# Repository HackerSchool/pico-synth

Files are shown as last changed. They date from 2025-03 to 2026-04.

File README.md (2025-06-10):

# pico-synth
The Pico-Synth Board v0.1 is the first version of a Raspberry Pi Pico based synthesizer, featuring an I2S DAC with line-out, a 2x8 switch matrix with individual LEDs, four rotary encoders with switches, an OLED screen, and an SD card slot for optional storage. This fist iteration of the board was designed with a focus on low cost and component availability.

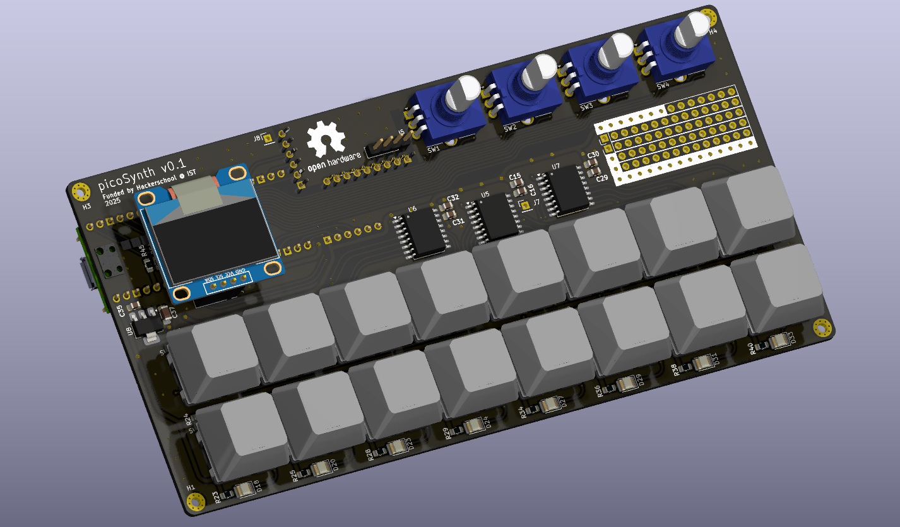
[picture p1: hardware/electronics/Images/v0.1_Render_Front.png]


## 📥 1. Clone the Repository & Initialize Submodules

```sh
git clone --recursive https://github.com/HackerSchool/pico-synth.git
cd pico-synth
```

If you already cloned without `--recursive`, initialize submodules manually:

```sh
git submodule update --init --recursive
```

## 📦 2. Install the Pico SDK and Pico Extras

### **Option 1: Install via Raspberry Pi Repo (Recommended on Raspberry Pi OS)**
```sh
sudo apt install cmake gcc-arm-none-eabi libnewlib-arm-none-eabi build-essential
```

### **Option 2: Manually Install (For Other Linux/Windows/macOS)**
#### **Clone & Set Up the Pico SDK**
```sh
mkdir -p ~/pico && cd ~/pico
git clone --recursive https://github.com/raspberrypi/pico-sdk.git
cd pico-sdk
git submodule update --init
```

#### **Clone & Set Up Pico Extras**
```sh
cd ~/pico
git clone --recursive https://github.com/raspberrypi/pico-extras.git
```

## 🌍 3. Set Environment Variables (Each Terminal Session)

Before building, set the paths so CMake can find the SDK and extras:

```sh
export PICO_SDK_PATH=~/pico/pico-sdk
export PICO_EXTRAS_PATH=~/pico/pico-extras
```

To make this **permanent**, add these lines to `~/.bashrc` or `~/.zshrc`:

```sh
echo 'export PICO_SDK_PATH=~/pico/pico-sdk' >> ~/.bashrc
echo 'export PICO_EXTRAS_PATH=~/pico/pico-extras' >> ~/.bashrc
source ~/.bashrc
```

## 🛠 4. Build the Project

1. **Create a Build Directory**
```sh
mkdir -p build && cd build
```

2. **Run CMake to Configure the Build**
```sh
cmake ..
```
if using ninja on windows:
```sh
cmake -G "Ninja" ..
```
3. **Compile the Code**
```sh
make -j$(nproc)
```
if using ninja on windows:
```sh
ninja
```
## 🔥 5. Flash to the Raspberry Pi Pico

### **Step 1: Put the Pico in Bootloader Mode**
- Hold down the **BOOTSEL** button on the Pico.
- Plug it into your computer via **USB**.
- It should appear as a **USB mass storage device** (RPI-RP2).

### **Step 2: Copy the `.uf2` Binary to the Pico**

Once built, the `pico-synth` binary (`.uf2` file) will be in `build/`:
```sh
cp build/pico-synth.uf2 /media/$USER/RPI-RP2/
```

The Pico will automatically reboot and start running the synthesizer!

---

## 🛠 Troubleshooting

- **"pico_sdk_import.cmake not found" error?**
  - Make sure `PICO_SDK_PATH` is set correctly.
  - Try running `source ~/.bashrc`.

- **No `*.uf2` file after `make`?**
  - Check the build log for errors.
  - Ensure `pico_enable_stdio_usb(${bin_name} 1)` is set in `CMakeLists.txt`.

---

## 📜 License
[GPLV3 License](LICENSE)

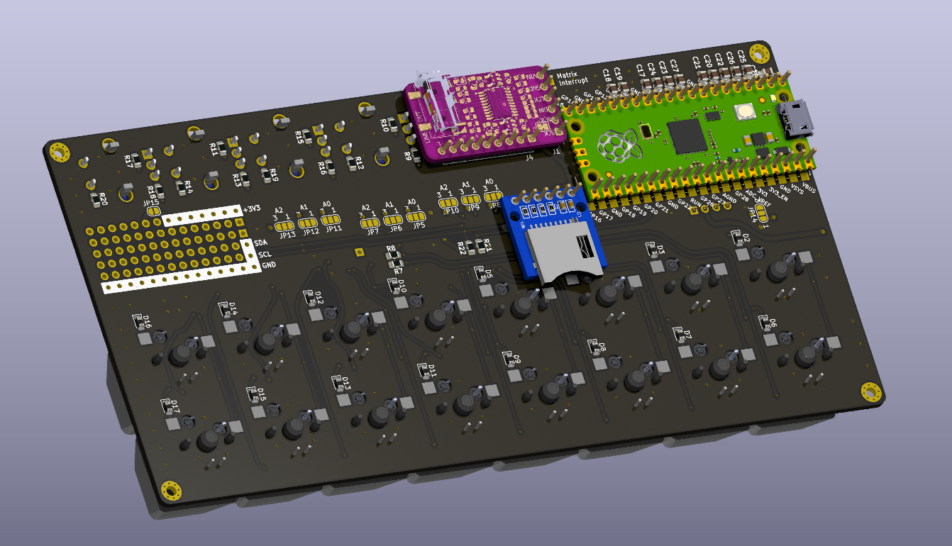
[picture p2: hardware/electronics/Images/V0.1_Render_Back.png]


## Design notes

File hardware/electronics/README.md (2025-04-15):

# Pico Synth Hardware

The Pico-Synth Board v0.1 is the first version of the synthesizer, featuring a DAC with line-out, a 4x4 switch matrix with individual LEDs, four rotary encoders with switches, an OLED screen, and an SD card slot for optional storage. This fist iteration of the board was designed with a focus on low cost and component availability.



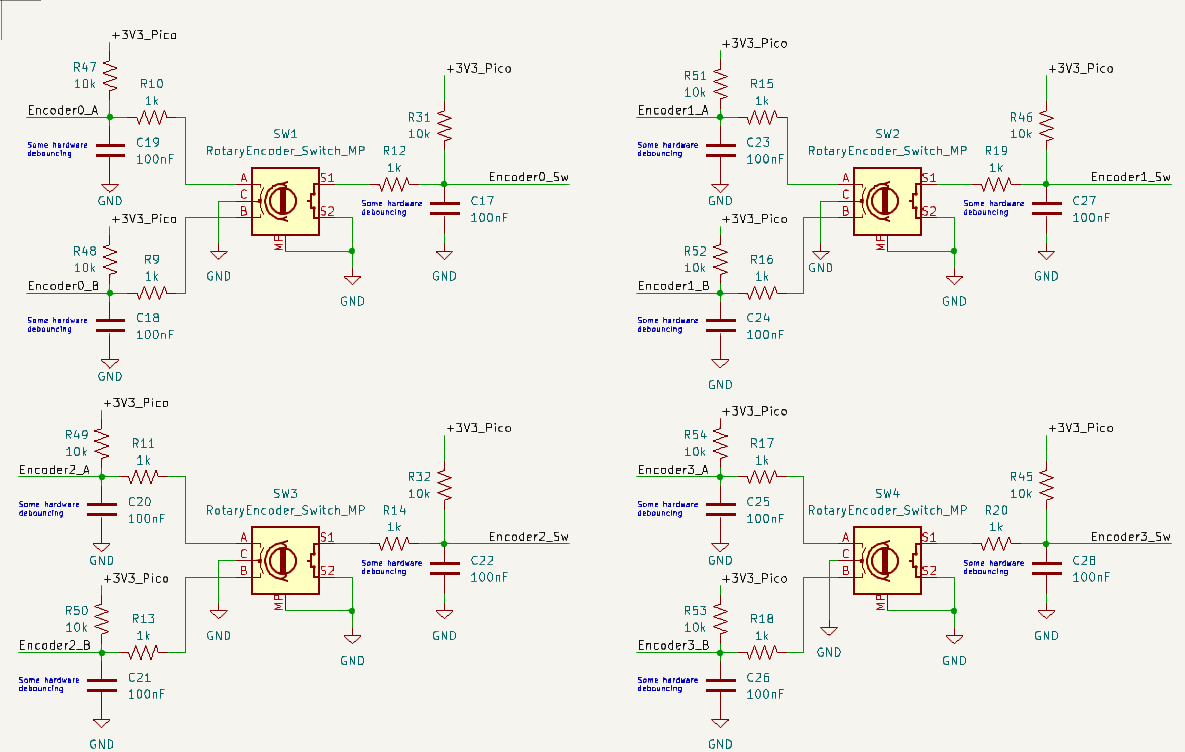
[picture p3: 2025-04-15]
hardware/electronics/Images/Encoders.png

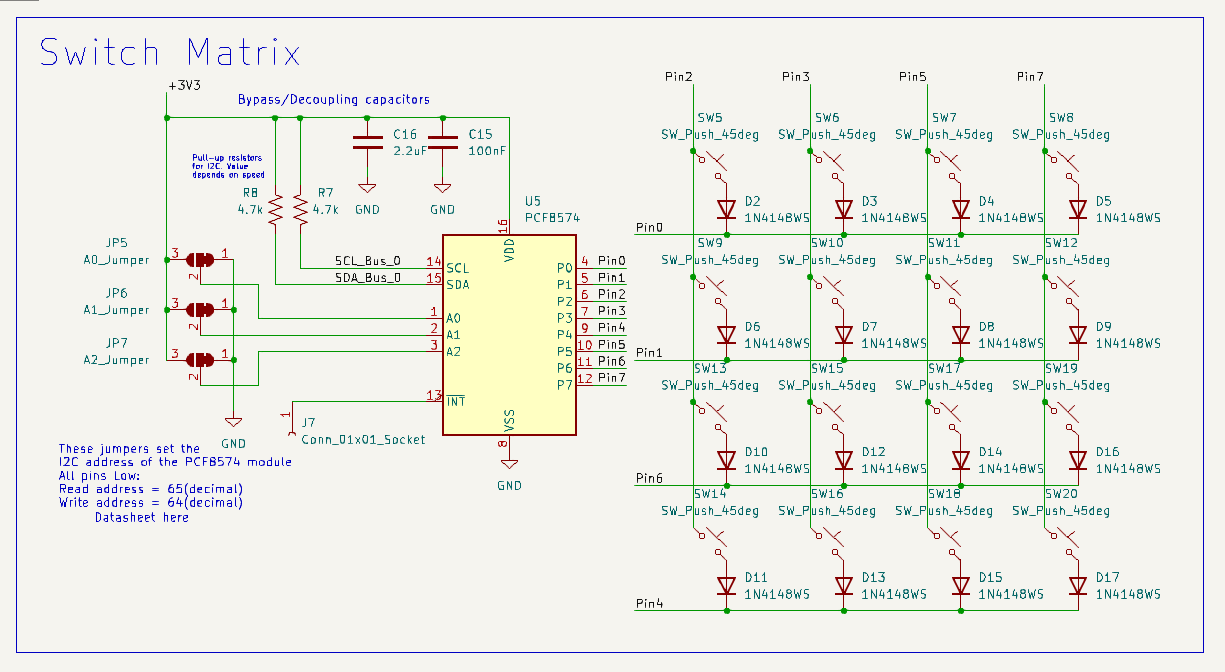
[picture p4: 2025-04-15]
hardware/electronics/Images/Switches.png

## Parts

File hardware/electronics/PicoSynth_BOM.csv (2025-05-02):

Reference | Value | Datasheet | Footprint | Qty | DNP
C15,C17,C18,C19,C20,C21,C22,C23,C24,C25,C26,C27,C28,C30,C32,C36 | 100nF | ~ | Cern_Ignition:C_0805_2012Metric_Pad1.18x1.45mm_HandSolder_modif | 16
C16,C29,C31,C35 | 2.2uF | ~ | Cern_Ignition:C_0805_2012Metric_Pad1.18x1.45mm_HandSolder_modif | 4
C37 | 10uF | ~ | Cern_Ignition:C_1206_3216Metric_Pad1.33x1.80mm_HandSolder_modif | 1
D2,D3,D4,D5,D6,D7,D8,D9,D10,D11,D12,D13,D14,D15,D16,D17 | 1N4148WS | https://www.vishay.com/docs/85751/1n4148ws.pdf | Diode_SMD:D_0805_2012Metric_Pad1.15x1.40mm_HandSolder | 16
D18,D19,D20,D21,D22,D23,D24,D25,D26,D27,D28,D29,D30,D31,D32,D33 | LED | ~ | LED_SMD:LED_1210_3225Metric_Pad1.42x2.65mm_HandSolder | 16
J1,J6 | Conn_01x06_Socket | ~ | Connector_PinSocket_2.54mm:PinSocket_1x06_P2.54mm_Vertical | 2
J3 | Conn_01x04_Socket | ~ | Connector_PinSocket_2.54mm:PinSocket_1x04_P2.54mm_Vertical | 1
J4 | Conn_01x09_Socket | ~ | Connector_PinSocket_2.54mm:PinSocket_1x09_P2.54mm_Vertical | 1
J5 | Line_Out | ~ | Connector_PinHeader_2.54mm:PinHeader_1x04_P2.54mm_Vertical | 1
J7,J8 | Conn_01x01_Socket | ~ | Connector_PinHeader_2.54mm:PinHeader_1x01_P2.54mm_Vertical | 2
J9,J10,J11,J12,J13,J14 | Conn_01x14_Socket | ~ | Connector_PinHeader_2.54mm:PinHeader_1x14_P2.54mm_Vertical | 6
JP5,JP8,JP11 | A0_Jumper | ~ | Jumper:SolderJumper-3_P1.3mm_Open_RoundedPad1.0x1.5mm_NumberLabels | 3
JP6,JP9,JP12 | A1_Jumper | ~ | Jumper:SolderJumper-3_P1.3mm_Open_RoundedPad1.0x1.5mm_NumberLabels | 3
JP7,JP10,JP13,JP14 | A2_Jumper | ~ | Jumper:SolderJumper-3_P1.3mm_Open_RoundedPad1.0x1.5mm_NumberLabels | 4
R7,R8,R21,R22 | 4.7k | ~ | Cern_Ignition:R_0805_2012Metric_Pad1.20x1.40mm_HandSolder_modif | 4
R9,R10,R11,R12,R13,R14,R15,R16,R17,R18,R19,R20,R23,R24,R25,R26,R27,R28,R29,R30,R33,R34,R35,R36,R37,R38,R39,R40 | 1k | ~ | Cern_Ignition:R_0805_2012Metric_Pad1.20x1.40mm_HandSolder_modif | 28
R31,R32,R45,R46,R47,R48,R49,R50,R51,R52,R53,R54 | 10k | ~ | Cern_Ignition:R_0805_2012Metric_Pad1.20x1.40mm_HandSolder_modif | 12
SW1,SW2,SW3,SW4 | RotaryEncoder_Switch_MP | ~ | Lame_Lib:RotaryEncoder_Alps_EC11E-Switch_Vertical_H20mm_CircularMountingHoles | 4
SW5,SW6,SW7,SW8,SW9,SW10,SW11,SW12,SW13,SW14,SW15,SW16,SW17,SW18,SW19,SW20 | SW_Push_45deg | ~ | Cherry_MX_switches:Cherry-MX_PCB-Mounted_LTST-A683CEGBW_Kailh_Socket_modif | 16
U1 | Pico |  | Pi_Pico:RPi_Pico_SMD_TH_No_Debug | 1
U5,U6,U7 | PCF8574 | http://www.nxp.com/docs/en/data-sheet/PCF8574_PCF8574A.pdf | Package_SO:SOIC-16W_7.5x10.3mm_P1.27mm | 3
U8 | AMS1117-3.3 | http://www.advanced-monolithic.com/pdf/ds1117.pdf | Package_TO_SOT_SMD:SOT-223-3_TabPin2 | 1

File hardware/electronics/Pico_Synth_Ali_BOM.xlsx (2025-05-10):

Qty Multiplier | 5 | i.e multiplier for the number of boards |  |  |  | Total Price (5 Boards) | 99.66
Cor: |  |  |  |  |  | Price Per Board | 19.932
 | Só encomendar caso acabe stock no lab
 | Encomendado
Modules
Ref | Name | Qty | Total Qty | Price | Total Price | Link
U1 | Raspberry Pi Pico | 1 | 5 | 2.19 | 10.95 | https://www.aliexpress.com/ssr/300000512/BundleDeals2?productIds=1005006309595439:12000036707152536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
 | I2S Audio Dac | 1 | 5 | 2.19 | 10.95 | https://www.aliexpress.com/ssr/300000512/BundleDeals2?productIds=1005007477490325:12000040987885705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
 | SD Card Module | 1 | 5 | 0.92 | 4.6 | https://pt.aliexpress.com/item/1005006997146471.html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
 | OLED Display | 1 | 5 | 1.59 | 7.95 | https://www.aliexpress.com/ssr/300000512/BundleDeals2?productIds=1005006365881525:12000036912059235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
Components
Ref | Name | Qty | Total Qty | Price | Total Price | Link
U5,U6,U7 | PCF8574 | 3 | 15 | 1.97 | 5.91 | https://pt.aliexpress.com/item/1005006991816164.html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
U8 | AMS1117-3.3 | 1 | 5 | 2.11 | 2.11 | https://pt.aliexpress.com/item/1005007537334074.html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
SW1,SW2,SW3,SW4 | RotaryEncoder_Switch_MP | 4 | 20 | 2.47 | 9.88 | https://pt.aliexpress.com/item/1005005983134515.html?scm_id=1007.40050.354490.0&scm-url=1007.40050.354490.0
D18,D19,D20,D21,D22,D23,D24,D25,D26,D27,D28,D29,D30,D31,D32,D33 | LED SMD | 16 | 80 | 1.44 | 1.44 | https://pt.aliexpress.com/item/1005005975758189.html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
D2,D3,D4,D5,D6,D7,D8,D9,D10,D11,D12,D13,D14,D15,D16,D17 | 1N4148WS SOD-323 | 16 | 80 | 1.81 | 1.81 | https://pt.aliexpress.com/item/1005007160563285.html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
C15,C17,C18,C19,C20,C21,C22,C23,C24,C25,C26,C27,C28,C30,C32,C36 | 100nF | 16 | 80 | 1.39 | 1.39 | https://pt.aliexpress.com/item/1005005690917856.html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
C16,C29,C31,C35 | 2.2uF | 4 | 20 | 1.47 | 1.47 | https://pt.aliexpress.com/item/1005005690917856.html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
C37 | 10uF | 1 | 5 | 1.46 | 1.46 | https://pt.aliexpress.com/item/1005005690917856.html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
R7,R8,R21,R22 | 4.7k | 4 | 20 | 1.24 | 1.24 | https://pt.aliexpress.com/item/1005006996501198.html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
R9,R10,R11,R12,R13,R14,R15,R16,R17,R18,R19,R20,R23,R24,R25,R26,R27,R28,R29,R30,R33,R34,R35,R36,R37,R38,R39,R40 | 1k | 28 | 140 | 1.24 | 2.48 | https://pt.aliexpress.com/item/1005006996501198.html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
R31,R32,R45,R46,R47,R48,R49,R50,R51,R52,R53,R54 | 10k | 12 | 60 | 1.33 | 1.33 | https://pt.aliexpress.com/item/1005006996501198.html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
 | Header Female (2.54 pitch) | 69 | 345 | 1.79 | 1.79 | https://www.aliexpress.com/ssr/300000512/BundleDeals2?productIds=1005007235591794:12000039908542821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
Switches
 | Kailh Hot Swap | 16 | 80 | 5.54 | 5.54 | https://pt.aliexpress.com/item/1005002637150446.html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
 | Outemu Switches | 16 | 80 | 12.99 | 12.99 | https://pt.aliexpress.com/item/1005007345651159.html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
 | Keycaps (10pcs) | 16 | 80 | 4.04 | 16.16 | https://pt.aliexpress.com/item/1005007683242914.html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 (https://pt.aliexpress.com/item/1005005513800132.html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)

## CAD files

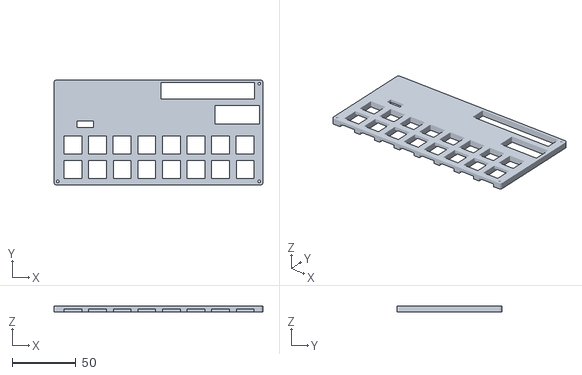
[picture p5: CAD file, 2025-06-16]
hardware/electronics/case0.3-PicoSynth-front-cover.stl
164.0 x 82.4 x 5.00

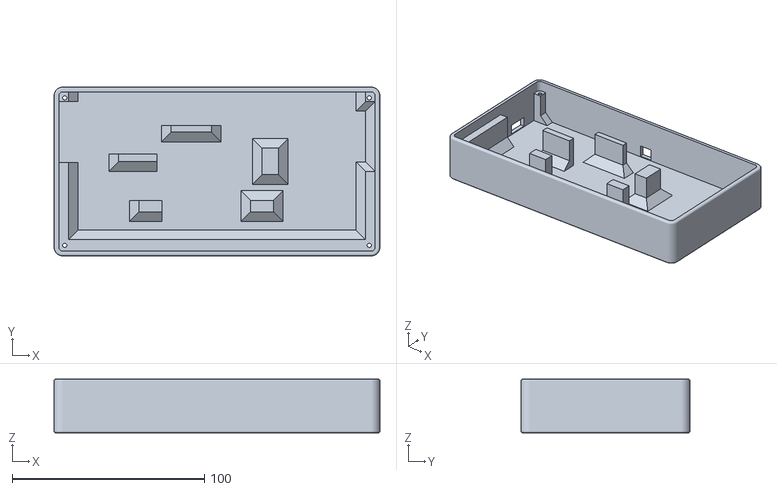
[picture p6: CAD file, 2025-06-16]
hardware/electronics/case0.3-PicoSynth-back-cover.stl
169.4 x 87.8 x 28.0

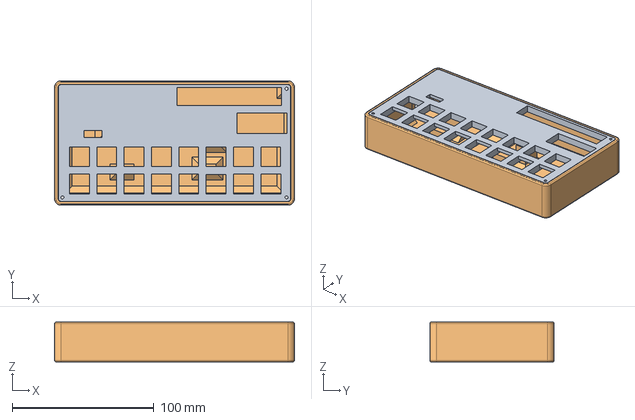
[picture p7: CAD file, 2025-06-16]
hardware/electronics/case2.FCStd
169.4 x 87.8 x 28.0 mm
front-cover
back-cover

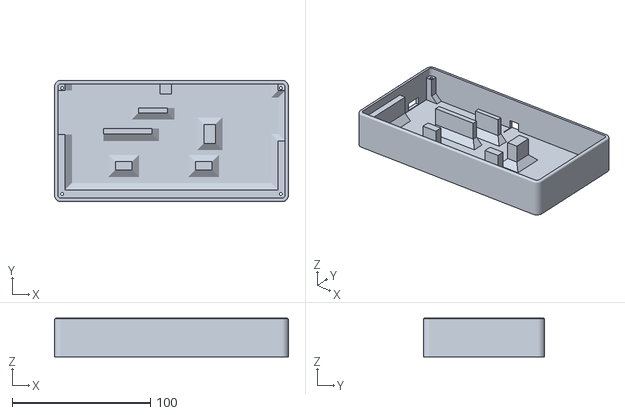
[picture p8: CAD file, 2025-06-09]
hardware/electronics/case2-PicoSynth-back-cover.stl
169.4 x 87.8 x 28.0

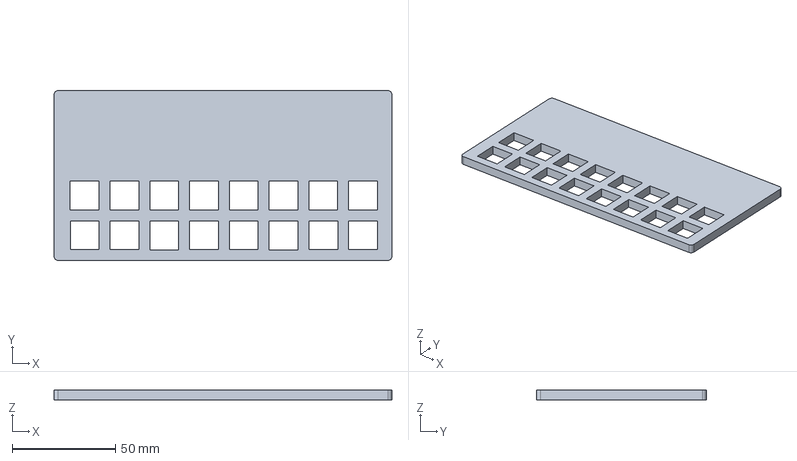
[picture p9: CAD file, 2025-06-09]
hardware/electronics/case.FCStd
164.0 x 82.4 x 5.00 mm

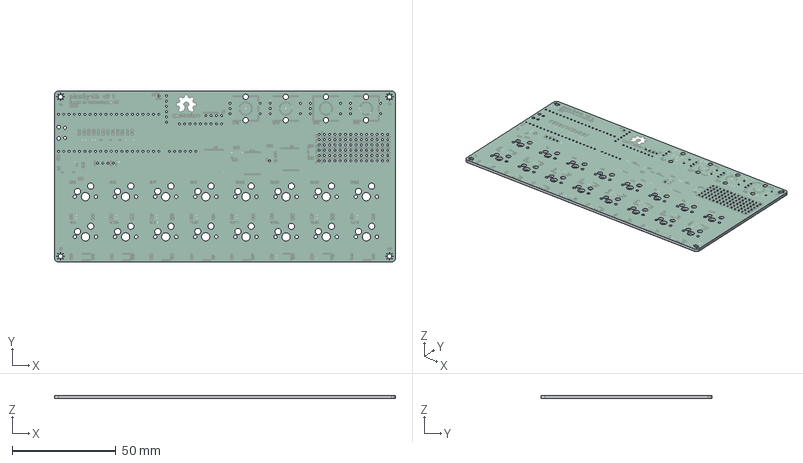
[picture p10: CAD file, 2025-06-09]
hardware/electronics/PicoSynth.step
164.0 x 82.4 x 1.66 mm
PicoSynth_silkscreen
PicoSynth_soldermask
PicoSynth_PCB

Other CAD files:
hardware/electronics/case0.2-PicoSynth-back-cover.stl
hardware/electronics/case2-PicoSynth-front-cover.stl
hardware/electronics/case0.2-PicoSynth-front-cover.stl

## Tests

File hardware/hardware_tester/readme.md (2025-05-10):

# Hardware Tester
The idea of the hardware tester was to develop a super simple firmware prototype that could be used to test all the functionalities of the synth, as soon as a PCB is assembled.
 
To use the hardware tester:
1. Turn on the Pico in BOOTSEL mode (connect to computer while pressing the "boot" button)
2. Copy the following files to the Pico drive:

- [main.py](main.py)
- [ssd1306.py](ssd1306.py)
- [micropython environment](RPI_PICO-20250415-v1.25.0.uf2)

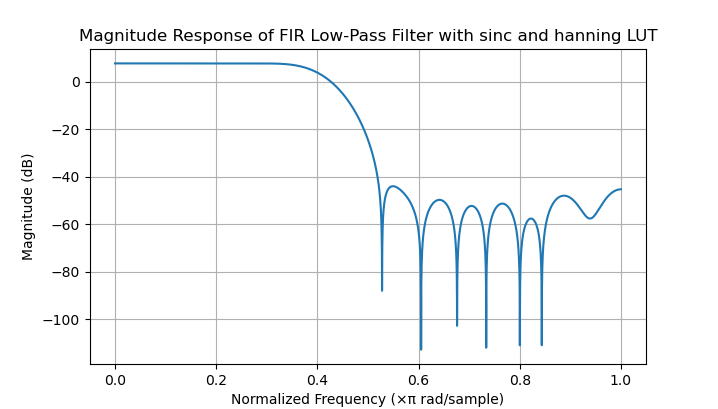
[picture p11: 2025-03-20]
filter-test/FIR_LowPass_LUT.png

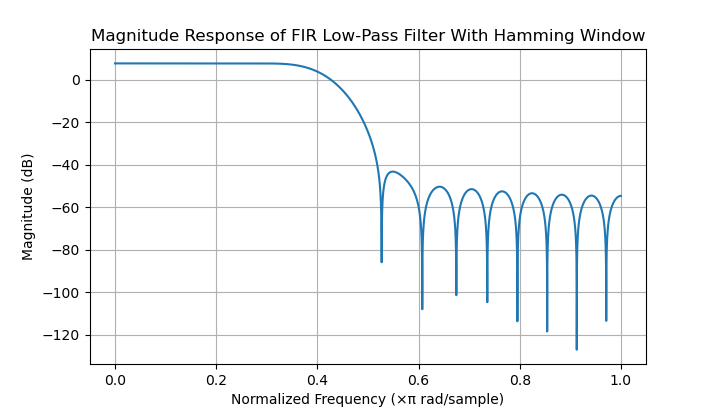
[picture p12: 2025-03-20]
filter-test/FIR_LowPass.png

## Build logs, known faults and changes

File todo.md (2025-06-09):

- software bootloader - ok, mandar um b por serial
- state machine/ menus thing
- Midi out
- Sequencer

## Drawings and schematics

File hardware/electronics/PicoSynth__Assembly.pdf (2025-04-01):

# 2025 picoSynth v0.1

A

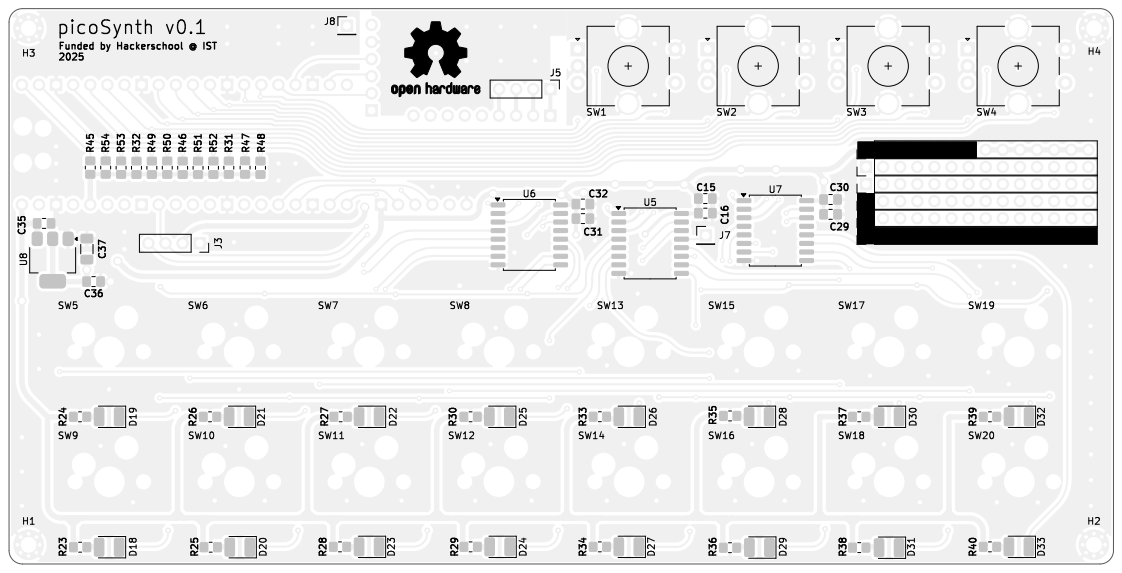
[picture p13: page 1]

Id: 1/1 Title: File: PicoSynth.kicad_pcb Sheet: Black And White TOP

J4 R9 D17 1 | 2 | 3 | 4 | 5 | 6

A

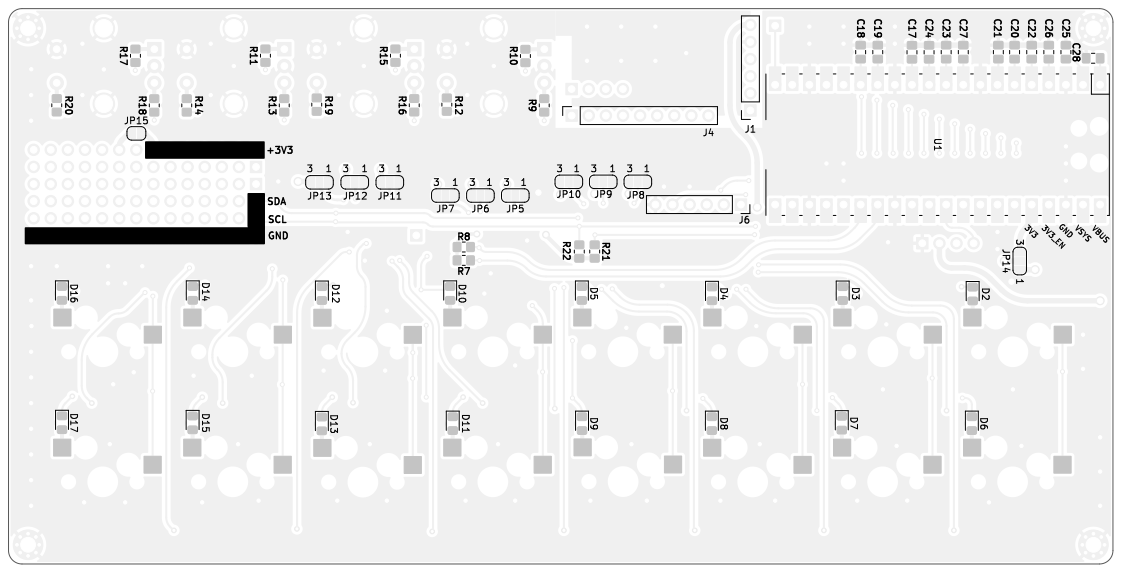
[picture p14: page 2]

J4 R9 D17 1 | 2 | 3 | 4 | 5 | 6

A

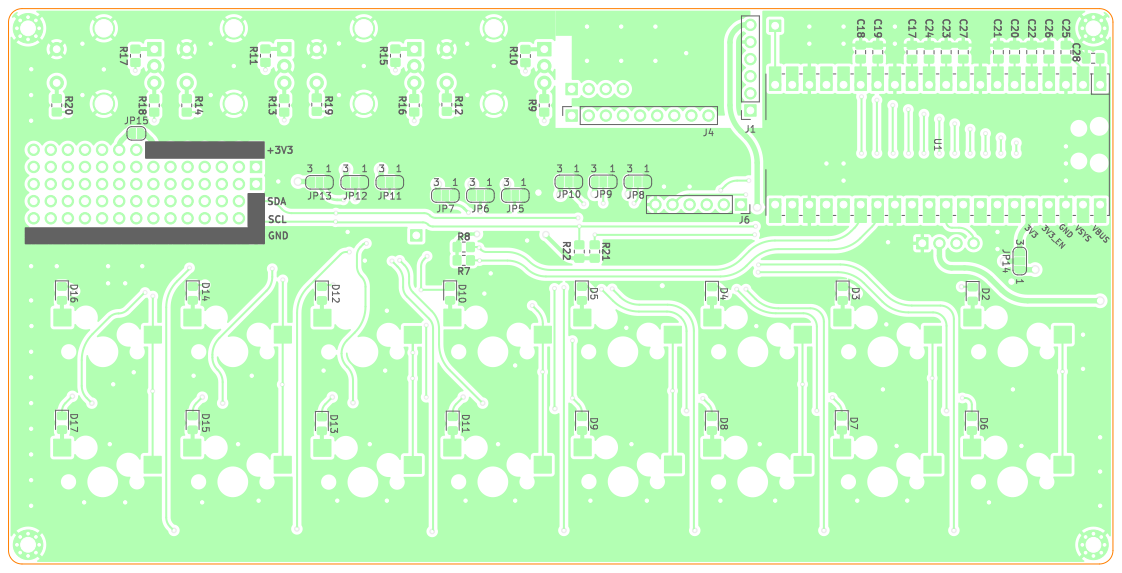
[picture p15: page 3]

# 2025 picoSynth v0.1

A

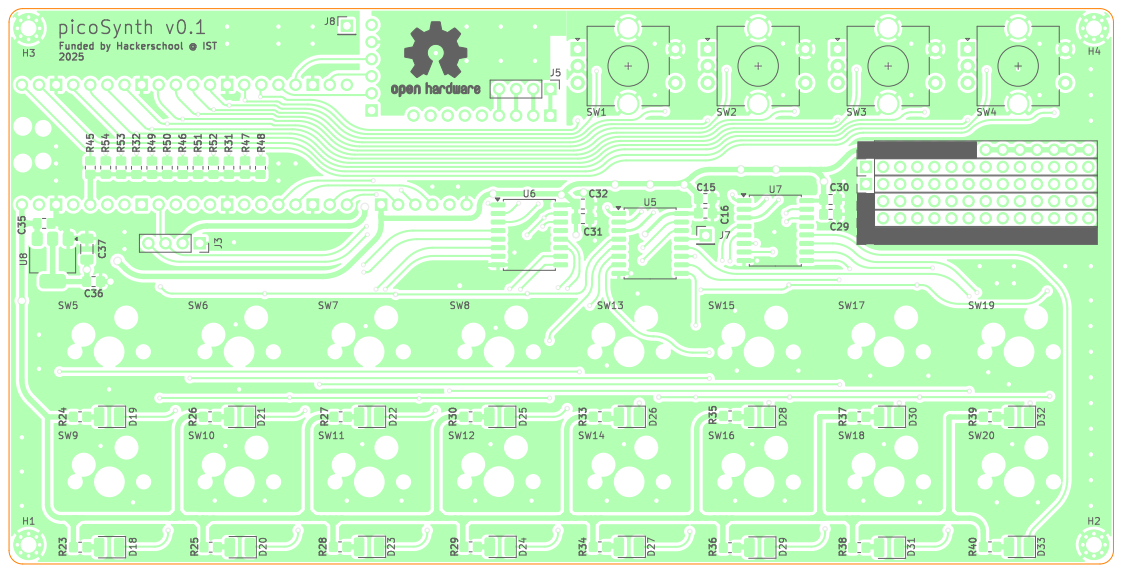
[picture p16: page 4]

Id: 1/1 Title: File: PicoSynth.kicad_pcb Sheet: Colored TOP

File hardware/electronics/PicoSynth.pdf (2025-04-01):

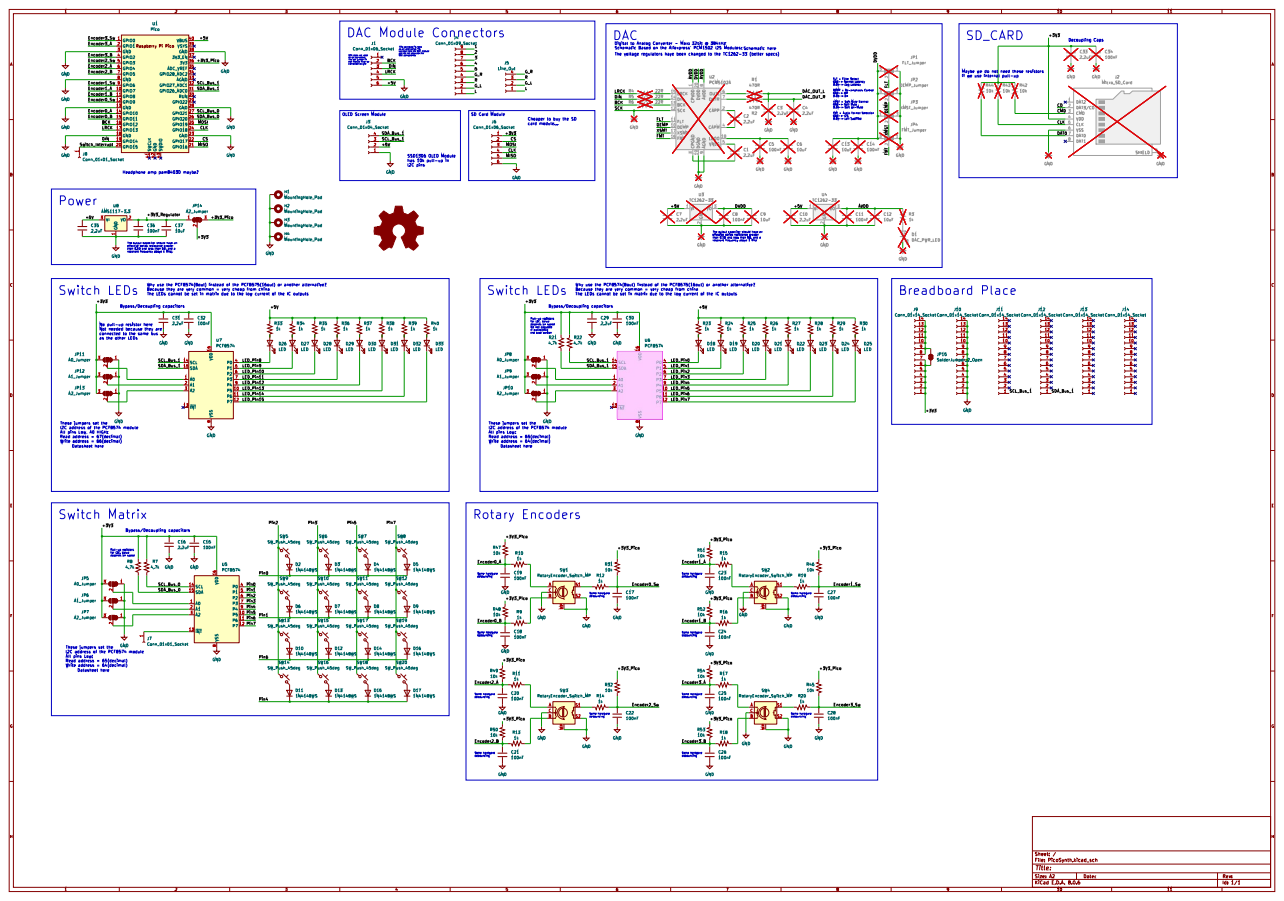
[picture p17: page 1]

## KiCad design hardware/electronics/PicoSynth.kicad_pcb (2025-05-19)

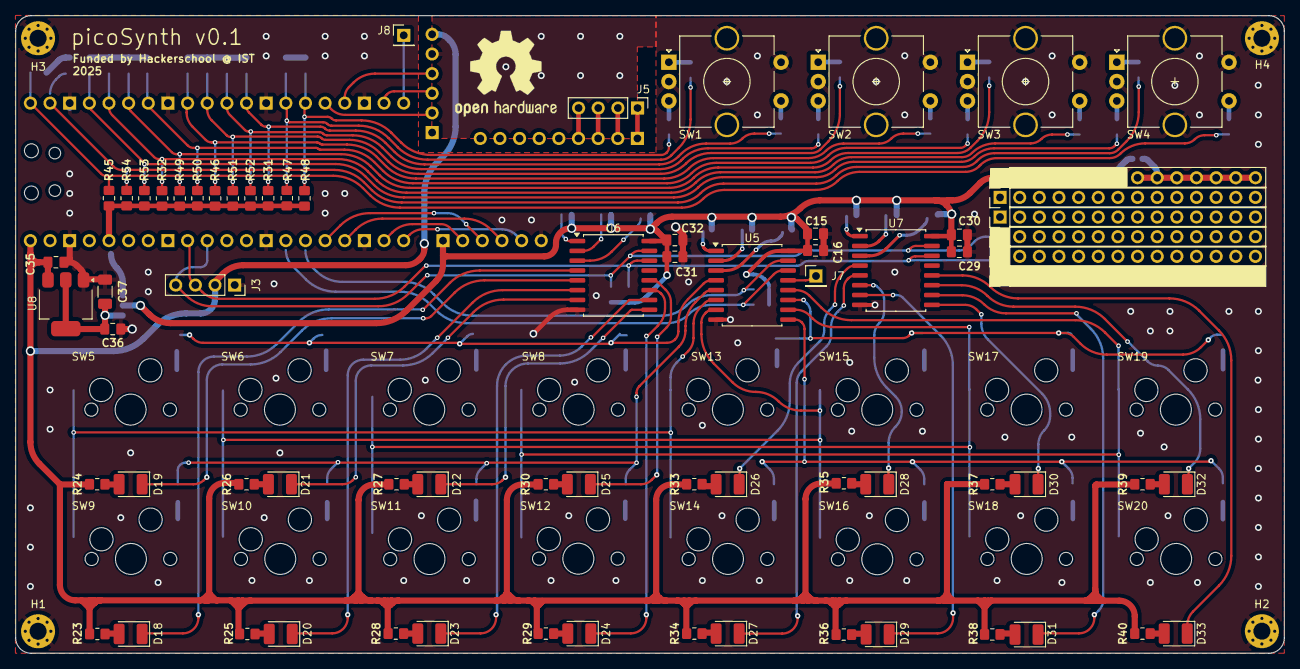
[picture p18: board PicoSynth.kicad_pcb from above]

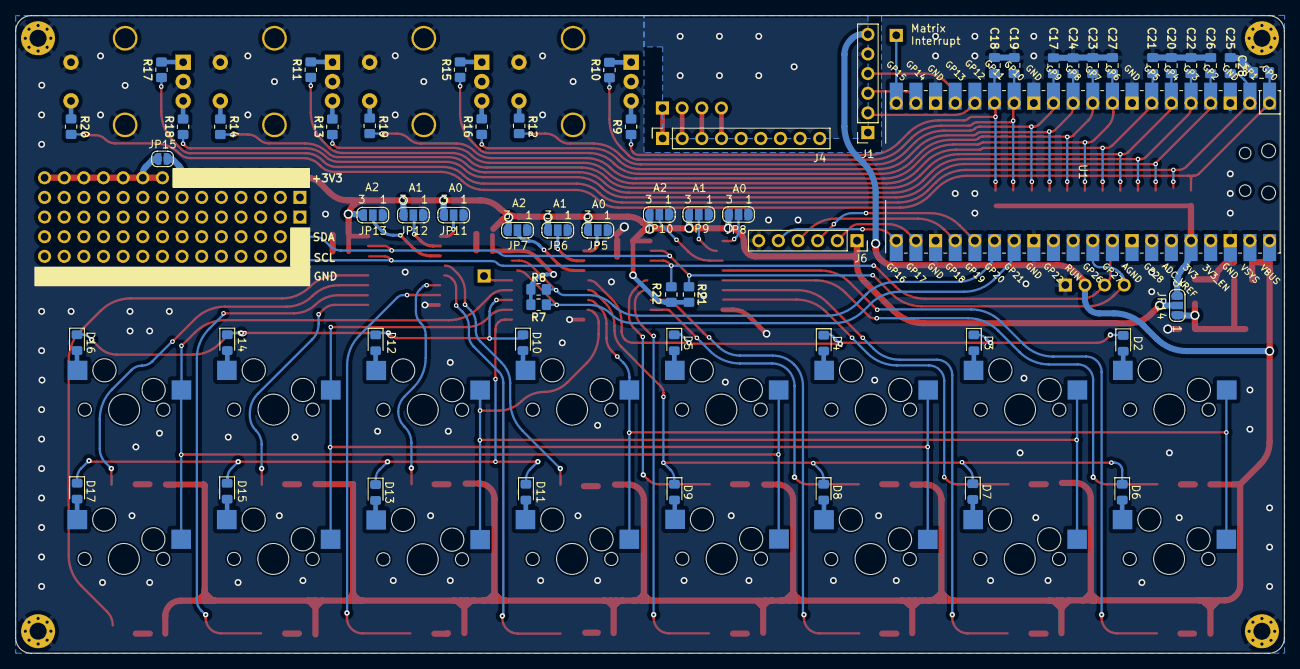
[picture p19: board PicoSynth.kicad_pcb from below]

Board: 2 copper layers, 164.0 x 82.4 mm, 150 parts (59 on the bottom side), 112 nets.

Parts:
C15, C17, C18, C19, C20, C21, C22, C23, C24, C25, C26, C27, C28, C30, C32, C36: 100nF; C_0805_2012Metric_Pad1.18x1.45mm_HandSolder_modif
C16, C29, C31, C35: 2.2uF; C_0805_2012Metric_Pad1.18x1.45mm_HandSolder_modif
C37: 10uF; C_1206_3216Metric_Pad1.33x1.80mm_HandSolder_modif
D2, D3, D4, D5, D6, D7, D8, D9, D10, D11, D12, D13, D14, D15, D16, D17: 1N4148WS; D_0805_2012Metric_Pad1.15x1.40mm_HandSolder
D18, D19, D20, D21, D22, D23, D24, D25, D26, D27, D28, D29, D30, D31, D32, D33: LED; LED_1210_3225Metric_Pad1.42x2.65mm_HandSolder
H1, H2, H3, H4: MountingHole_Pad; MountingHole_2.2mm_M2_Pad_Via
J1, J6: Conn_01x06_Socket; PinSocket_1x06_P2.54mm_Vertical
J3: Conn_01x04_Socket; PinSocket_1x04_P2.54mm_Vertical
J4: Conn_01x09_Socket; PinSocket_1x09_P2.54mm_Vertical
J5: Line_Out; PinHeader_1x04_P2.54mm_Vertical
J7, J8: Conn_01x01_Socket; PinHeader_1x01_P2.54mm_Vertical
J9, J10, J11, J12, J13, J14: Conn_01x14_Socket; PinHeader_1x14_P2.54mm_Vertical
JP5, JP8, JP11: A0_Jumper; SolderJumper-3_P1.3mm_Open_RoundedPad1.0x1.5mm_NumberLabels
JP6, JP9, JP12: A1_Jumper; SolderJumper-3_P1.3mm_Open_RoundedPad1.0x1.5mm_NumberLabels
JP7, JP10, JP13, JP14: A2_Jumper; SolderJumper-3_P1.3mm_Open_RoundedPad1.0x1.5mm_NumberLabels
JP15: SolderJumper_2_Open; SolderJumper-2_P1.3mm_Open_RoundedPad1.0x1.5mm
R7, R8, R21, R22: 4.7k; R_0805_2012Metric_Pad1.20x1.40mm_HandSolder_modif
R9, R10, R11, R12, R13, R14, R15, R16, R17, R18, R19, R20, R23, R24, R25, R26, R27, R28, R29, R30, R33, R34, R35, R36, R37, R38, R39, R40: 1k; R_0805_2012Metric_Pad1.20x1.40mm_HandSolder_modif
R31, R32, R45, R46, R47, R48, R49, R50, R51, R52, R53, R54: 10k; R_0805_2012Metric_Pad1.20x1.40mm_HandSolder_modif
SW1, SW2, SW3, SW4: RotaryEncoder_Switch_MP; RotaryEncoder_Alps_EC11E-Switch_Vertical_H20mm_CircularMoun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
SW5, SW6, SW7, SW8, SW9, SW10, SW11, SW12, SW13, SW14, SW15, SW16, SW17, SW18, SW19, SW20: SW_Push_45deg; Cherry-MX_PCB-Mounted_LTST-A683CEGBW_Kailh_Socket_modif
U1: Pico; RPi_Pico_SMD_TH_No_Debug
U5, U6, U7: PCF8574; SOIC-16W_7.5x10.3mm_P1.27mm
U8: AMS1117-3.3; SOT-223-3_TabPin2

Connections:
/+3V3: C15.1, C16.1, C29.1, C30.1, C31.1, C32.1, J6.1, J9.1, J9.2, J9.3, J9.4, J9.5, J9.6, J9.7, JP5.3 (B), JP6.3 (B), JP7.3 (B), JP8.3 (B), JP9.3 (B), JP10.3 (B), JP11.3 (B), JP12.3 (B), JP13.3 (B), JP14.2 (C), JP15.1 (A), R7.1, R8.1, R21.1, R22.1, U5.16 (VDD), U6.16 (VDD), U7.16 (VDD)
/+3V3_Pico: JP14.3 (B), R31.2, R32.2, R45.2, R46.2, R47.2, R48.2, R49.2, R50.2, R51.2, R52.2, R53.2, R54.2, U1.36 (3V3)
/+3V3_Regulator: C36.1, C37.1, JP14.1 (A), U8.2 (VO)
/+5V: C35.1, J1.6, J3.2, R23.1, R24.1, R25.1, R26.1, R27.1, R28.1, R29.1, R30.1, R33.1, R34.1, R35.1, R36.1, R37.1, R38.1, R39.1, R40.1, U1.40 (VBUS), U8.3 (VI)
/BCK: J1.2, U1.16 (GPIO12)
/CLK: J6.4, U1.24 (GPIO18)
/CS: J6.2, U1.22 (GPIO17)
/DIN: J1.3, U1.19 (GPIO14)
/Encoder0_A: C19.1, R10.1, R47.1, U1.14 (GPIO10)
/Encoder0_B: C18.1, R9.1, R48.1, U1.15 (GPIO11)
/Encoder0_Sw: C17.1, R12.2, R31.1, U1.12 (GPIO9)
/Encoder1_A: C23.1, R15.1, R51.1, U1.10 (GPIO7)
/Encoder1_B: C24.1, R16.1, R52.1, U1.11 (GPIO8)
/Encoder1_Sw: C27.1, R19.2, R46.1, U1.9 (GPIO6)
/Encoder2_A: C20.1, R11.1, R49.1, U1.6 (GPIO4)
/Encoder2_B: C21.1, R13.1, R50.1, U1.7 (GPIO5)
/Encoder2_Sw: C22.1, R14.2, R32.1, U1.5 (GPIO3)
/Encoder3_A: C25.1, R17.1, R54.1, U1.2 (GPIO1)
/Encoder3_B: C26.1, R18.1, R53.1, U1.4 (GPIO2)
/Encoder3_Sw: C28.1, R20.2, R45.1, U1.1 (GPIO0)
/G_L: J4.2, J5.2
/G_R: J4.4, J5.4
/L: J4.1, J5.1
/LED_Pin0: D18.1 (K), U6.4 (P0)
/LED_Pin1: D19.1 (K), U6.5 (P1)
/LED_Pin2: D20.1 (K), U6.6 (P2)
/LED_Pin3: D21.1 (K), U6.7 (P3)
/LED_Pin4: D22.1 (K), U6.9 (P4)
/LED_Pin5: D23.1 (K), U6.10 (P5)
/LED_Pin6: D24.1 (K), U6.11 (P6)
/LED_Pin7: D25.1 (K), U6.12 (P7)
/LED_Pin8: D26.1 (K), U7.4 (P0)
/LED_Pin9: D27.1 (K), U7.5 (P1)
/LED_Pin10: D28.1 (K), U7.6 (P2)
/LED_Pin11: D29.1 (K), U7.7 (P3)
/LED_Pin12: D30.1 (K), U7.9 (P4)
/LED_Pin13: D31.1 (K), U7.10 (P5)
/LED_Pin14: D32.1 (K), U7.11 (P6)
/LED_Pin15: D33.1 (K), U7.12 (P7)
/LRCK: J1.4, U1.17 (GPIO13)
/MISO: J6.5, U1.21 (GPIO16)
/MOSI: J6.3, U1.25 (GPIO19)
/Pin0: D2.1 (K), D3.1 (K), D4.1 (K), D5.1 (K), U5.4 (P0)
/Pin1: D6.1 (K), D7.1 (K), D8.1 (K), D9.1 (K), U5.5 (P1)
/Pin2: SW5.1, SW9.1, SW13.1, SW14.1, U5.6 (P2)
/Pin3: SW6.1, SW10.1, SW15.1, SW16.1, U5.7 (P3)
/Pin4: D11.1 (K), D13.1 (K), D15.1 (K), D17.1 (K), U5.9 (P4)
/Pin5: SW7.1, SW11.1, SW17.1, SW18.1, U5.10 (P5)
/Pin6: D10.1 (K), D12.1 (K), D14.1 (K), D16.1 (K), U5.11 (P6)
/Pin7: SW8.1, SW12.1, SW19.1, SW20.1, U5.12 (P7)
/R: J4.3, J5.3
/SCL_Bus_0: R7.2, U1.27 (GPIO21), U5.14 (SCL)
/SCL_Bus_1: J3.3, J11.1, R22.2, U1.32 (GPIO27_ADC1), U6.14 (SCL), U7.14 (SCL)
/SDA_Bus_0: R8.2, U1.26 (GPIO20), U5.15 (SDA)
/SDA_Bus_1: J3.4, J12.1, R21.2, U1.31 (GPIO26_ADC0), U6.15 (SDA), U7.15 (SDA)
/Switch_Interrupt: J8.1, U1.20 (GPIO15)
GND: C15.2, C16.2, C17.2, C18.2, C19.2, C20.2, C21.2, C22.2, C23.2, C24.2, C25.2, C26.2, C27.2, C28.2, C29.2, C30.2, C31.2, C32.2, C35.2, C36.2, C37.2, H1.1, H2.1, H3.1, H4.1, J1.5, J3.1, J6.6, J10.1, J10.2, J10.3, J10.4, J10.5, J10.6, J10.7, J10.8, J10.9, J10.10, J10.11, J10.12, J10.13, J10.14, JP5.1 (A), JP6.1 (A), JP7.1 (A), JP8.1 (A), JP9.1 (A), JP10.1 (A), JP11.1 (A), JP12.1 (A), JP13.1 (A), SW1.C, SW1.MP, SW1.S2, SW2.C, SW2.MP, SW2.S2, SW3.C, SW3.MP, SW3.S2, SW4.C, SW4.MP, SW4.S2, U1.3 (GND), U1.8 (GND), U1.13 (GND), U1.18 (GND), U1.23 (GND), U1.28 (GND), U1.38 (GND), U5.8 (VSS), U6.8 (VSS), U7.8 (VSS), U8.1 (GND)
unnamed: D2.2 (A), SW5.2
unnamed: D3.2 (A), SW6.2
unnamed: D4.2 (A), SW7.2
unnamed: D5.2 (A), SW8.2
unnamed: D6.2 (A), SW9.2
unnamed: D7.2 (A), SW10.2
unnamed: D8.2 (A), SW11.2
unnamed: D9.2 (A), SW12.2
unnamed: D10.2 (A), SW13.2
unnamed: D11.2 (A), SW14.2
unnamed: D12.2 (A), SW15.2
unnamed: D13.2 (A), SW16.2
unnamed: D14.2 (A), SW17.2
unnamed: D15.2 (A), SW18.2
unnamed: D16.2 (A), SW19.2
unnamed: D17.2 (A), SW20.2
unnamed: D18.2 (A), R23.2
unnamed: D19.2 (A), R24.2
unnamed: D20.2 (A), R25.2
unnamed: D21.2 (A), R26.2
unnamed: D22.2 (A), R27.2
unnamed: D23.2 (A), R28.2
unnamed: D24.2 (A), R29.2
unnamed: D25.2 (A), R30.2
unnamed: D26.2 (A), R33.2
unnamed: D27.2 (A), R34.2
unnamed: D28.2 (A), R35.2
unnamed: D29.2 (A), R36.2
unnamed: D30.2 (A), R37.2
unnamed: D31.2 (A), R38.2
unnamed: D32.2 (A), R39.2
unnamed: D33.2 (A), R40.2
unnamed: J7.1, U5.13 (~INT)
unnamed: J9.8, J9.9, J9.10, J9.11, J9.12, J9.13, J9.14, JP15.2 (B)
unnamed: JP5.2 (C), U5.1 (A0)
unnamed: JP6.2 (C), U5.2 (A1)
unnamed: JP7.2 (C), U5.3 (A2)
unnamed: JP8.2 (C), U6.1 (A0)
unnamed: JP9.2 (C), U6.2 (A1)
unnamed: JP10.2 (C), U6.3 (A2)
unnamed: JP11.2 (C), U7.1 (A0)
unnamed: JP12.2 (C), U7.2 (A1)
unnamed: JP13.2 (C), U7.3 (A2)
unnamed: R9.2, SW1.B
unnamed: R10.2, SW1.A
unnamed: R11.2, SW3.A
unnamed: R12.1, SW1.S1
unnamed: R13.2, SW3.B
unnamed: R14.1, SW3.S1
unnamed: R15.2, SW2.A
unnamed: R16.2, SW2.B
unnamed: R17.2, SW4.A
unnamed: R18.2, SW4.B
unnamed: R19.1, SW2.S1
unnamed: R20.1, SW4.S1

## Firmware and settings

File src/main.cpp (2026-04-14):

#include <cstdint>
#include <pico/types.h>
#include <stdio.h>
#include <pico/stdlib.h>
#include <pico/time.h>
#include <stdlib.h>
#include <unistd.h>

#include "pico/audio.h"
#include "pico/bootrom.h"
#include "pico/multicore.h"
#include "pico/util/queue.h"

#include "hardware/clocks.h"
#include "hardware/pll.h"
#include "hardware/regs/addressmap.h"
#include "hardware/structs/clocks.h"

#include "fixed_point.h"
#include "tusb.h"
#include <bsp/board.h>

#include "HardwareManager.hpp"
#include "MidiHandler.hpp"
#include "Sampler.hpp"
#include "Sequencer.hpp"
#include "Synth.hpp"
#include "Ui.hpp"
#include "Wavetable.hpp"
#include "audio.h"
#include "config.hpp"

#include "diskio.h"    // FatFS disk I/O
#include "ff.h"        // FatFS
#include "hw_config.h" // SD card hardware config

#include <cstring>
#include <limits>

static audio_buffer_pool *ap = nullptr;

static queue_t midi_queue;
// static queue_t sample_trigger_queue;

Synth synth = Synth();
Sampler sampler;

std::array<int16_t, SAMPLES_PER_BUFFER> output;
std::array<int16_t, SAMPLES_PER_BUFFER> sampler_buffer;

static volatile uintptr_t core0_min_sp = std::numeric_limits<uintptr_t>::max();
static volatile uintptr_t core1_min_sp = std::numeric_limits<uintptr_t>::max();

static inline uintptr_t current_stack_pointer() {
    volatile uint8_t stack_probe = 0;
    return reinterpret_cast<uintptr_t>(&stack_probe);
}

static inline void sample_stack_usage_core0() {
    const uintptr_t sp = current_stack_pointer();
    if (sp < core0_min_sp) {
        core0_min_sp = sp;
    }
}

static inline void sample_stack_usage_core1() {
    const uintptr_t sp = current_stack_pointer();
    if (sp < core1_min_sp) {
        core1_min_sp = sp;
    }
}

static void print_ram_usage_percent() {
    uintptr_t min_sp = core0_min_sp;
    if (core1_min_sp < min_sp) {
        min_sp = core1_min_sp;
    }
    if (min_sp == std::numeric_limits<uintptr_t>::max()) {
        min_sp = current_stack_pointer();
    }

    const uintptr_t ram_base = static_cast<uintptr_t>(SRAM_BASE);
    const uintptr_t ram_end = static_cast<uintptr_t>(SRAM_END);
    if (min_sp < ram_base) min_sp = ram_base;
    if (min_sp > ram_end) min_sp = ram_end;

    // Low-memory usage grows upward (.data/.bss/heap), stack grows downward.
    uintptr_t heap_top = reinterpret_cast<uintptr_t>(sbrk(0));
    if (heap_top == static_cast<uintptr_t>(-1)) {
        heap_top = ram_base;
    }
    if (heap_top < ram_base) heap_top = ram_base;
    if (heap_top > ram_end) heap_top = ram_end;

    const uint32_t ram_total = static_cast<uint32_t>(ram_end - ram_base);
    uint32_t ram_used = static_cast<uint32_t>((heap_top - ram_base) +
                                              (ram_end - min_sp));
    if (ram_used > ram_total) ram_used = ram_total;
    const float ram_percent =
        ram_total == 0 ? 0.0f
                       : (100.0f * static_cast<float>(ram_used) /
                          static_cast<float>(ram_total));

    printf("RAM: %.1f%% (%lu/%lu bytes)\n", static_cast<double>(ram_percent),
           static_cast<unsigned long>(ram_used),
           static_cast<unsigned long>(ram_total));
}

void enter_bootsel_mode() {
    reset_usb_boot(0, 0); // Jump to BOOTSEL (UF2) mode
}

void setup_gpios(void) {

    i2c_init(i2c1, 400000);
    gpio_set_function(26, GPIO_FUNC_I2C);
    gpio_set_function(27, GPIO_FUNC_I2C);
    gpio_pull_up(26);
    gpio_pull_up(27);

    i2c_init(i2c0, 100 * 1000);
    gpio_set_function(20, GPIO_FUNC_I2C); // SDA
    gpio_set_function(21, GPIO_FUNC_I2C); // SCL
    gpio_pull_up(20);
    gpio_pull_up(21);
}

void audio_task(void) {
    // Clear accumulation buffer
    output.fill(0);

    // Render synth
    synth.out(output);

    sampler.out(sampler_buffer);

    // Mix sampler with synth, then run the shared FX chain on the full signal.
    // Use 64-bit accumulation to prevent overflow from multiple voices
    for (uint i = 0; i < SAMPLES_PER_BUFFER; i++) {
        int64_t mixed = (int64_t)output[i] + (int64_t)(sampler_buffer[i] >> 2);
        if (mixed > 32767)
            mixed = 32767;
        if (mixed < -32768)
            mixed = -32768;
        output[i] = (int16_t)mixed;
    }

    synth.process_fx(output);

    // Send to audio buffer (your existing code)
    audio_buffer_t *buffer = take_audio_buffer(ap, true);
    if (!buffer)
        return;

    // Ensure buffer size matches our audio generation size to prevent overflow
    if (buffer->max_sample_count != SAMPLES_PER_BUFFER) {
        panic("Audio buffer size mismatch: expected %lu, got %lu",
              (unsigned long)SAMPLES_PER_BUFFER,
              (unsigned long)buffer->max_sample_count);
    }

    uint8_t *sample_bytes = buffer->buffer->bytes;
    for (uint i = 0; i < buffer->max_sample_count; i++) {
        const int16_t left = output[i];
        const int16_t right = output[i];
        std::memcpy(sample_bytes + (i * 4), &left, sizeof(left));
        std::memcpy(sample_bytes + (i * 4) + sizeof(left), &right, sizeof(right));
    }
    buffer->sample_count = buffer->max_sample_count;
    give_audio_buffer(ap, buffer);
}

void audio_loop(void) {

    while (true) {
        sample_stack_usage_core1();
        uint8_t msg[4];
        while (queue_try_remove(&midi_queue, msg)) {
            synth.process_midi_packet(msg);
            // printf("Yo, on core 1, got a package\n");
        }
        audio_task();
    }
}

int main() {
    // Set up system clock for better audio
    pll_init(pll_usb, 1, 1536 * MHZ, 4, 4);
    clock_configure(clk_usb, 0, CLOCKS_CLK_USB_CTRL_AUXSRC_VALUE_CLKSRC_PLL_USB,
                    96 * MHZ, 48 * MHZ);
    clock_configure(clk_sys, CLOCKS_CLK_SYS_CTRL_SRC_VALUE_CLKSRC_CLK_SYS_AUX,
                    CLOCKS_CLK_SYS_CTRL_AUXSRC_VALUE_CLKSRC_PLL_USB, 150 * MHZ,
                    150 * MHZ);
    clock_configure(clk_peri, 0,
                    CLOCKS_CLK_PERI_CTRL_AUXSRC_VALUE_CLKSRC_PLL_SYS, 150 * MHZ,
                    150 * MHZ);

    // Initialize TinyUSB
    tusb_init();
    stdio_usb_init();

    // Initialize I2S audio output
    ap = audio_init();
    if (!ap) {
        panic("audio_init() failed - unable to initialize audio buffer pool");
    }

    setup_gpios();

    if (!sampler.init()) {
        printf("Sampler initialization failed!\n");
    }

    sampler.load_sample(0, "kick.wav");
    sampler.load_sample(1, "snare.wav");
    sampler.load_sample(2, "closehat.wav");
    sampler.load_sample(3, "crash.wav");
    sampler.load_sample(4, "kick.wav");

    static MidiHandler midi_handler(midi_queue);

    static HardwareManager hw;

    hw.init();

    static Sequencer seq(midi_handler, sampler);

    static UiHandler ui(hw, midi_handler, seq, sampler, synth);

    queue_init(&midi_queue, 4, 64);
    // queue_init(&sample_trigger_queue, sizeof(uint32_t), 16); // Add this line
    multicore_launch_core1(audio_loop);
    uint32_t last_ram_print_ms = to_ms_since_boot(get_absolute_time());

    while (true) {
        sample_stack_usage_core0();
        // Handle USB tasks
        tud_task();

        // Handle MIDI messages
        midi_handler.midi_task();

        hw.update();
        ui.update();
        seq.update();

        const uint32_t now_ms = to_ms_since_boot(get_absolute_time());
        if (now_ms - last_ram_print_ms >= 2000) {
            last_ram_print_ms = now_ms;
            print_ram_usage_percent();
        }

        int c = getchar_timeout_us(0);
        if (c >= 0) {
            if (c == 'q')
                for (int i = 0; i < 512; i++) {
                    printf("%f,\n\r", static_cast<double>(q24_to_float(sinc_table_fp[i])));
                }
            if (c == 'b')
                enter_bootsel_mode();
            // Trigger samples
            if (c == '1')
                sampler.trigger_player(0); // Trigger kick
            if (c == '2')
                sampler.trigger_player(1); // Trigger snare
            if (c == '3')
                sampler.trigger_player(2); // Trigger hihat
            if (c == '4')
                sampler.trigger_player(3); // Trigger crash
            if (c == '5')
                sampler.trigger_player(4); // Trigger kick
        }
    }

    return 0;
}

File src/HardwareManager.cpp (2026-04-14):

#include "HardwareManager.hpp"
#include "Wavetable.hpp"
#include "generated/engine_menu_bitmaps.hpp"
#include "ssd1306.h"
#include "ui/draw_utils.hpp"
#include <array>
#include <cstdint>
#include <cstdio>

uint8_t led_state_1 = 0xFF;
uint8_t led_state_2 = 0xFF;

const uint8_t COL_PINS[4] = {0, 1, 6, 4};
const uint8_t ROW_PINS[4] = {2, 3, 5, 7};

uint8_t LED_MAP[16] = {1, 3, 4, 7, 0, 2, 5, 6, 0, 2, 4, 6, 1, 3, 5, 7};

namespace {
constexpr int kDisplayWidth = 128;
constexpr int kDisplayHeight = 64;
constexpr int kAdsrArrowX[4] = {0, 52, 0, 52};
constexpr int kAdsrArrowY[4] = {36, 36, 44, 44};
constexpr int kChooseStateMain = 0;
constexpr int kChooseStateFxEdit = 2;
constexpr int kChooseStateAnalog = 3;
constexpr int kChooseStateLfo = 12;
constexpr int kChooseStateMidi = 4;
constexpr int kChooseStateSequencer = 5;
constexpr int kChooseStateSampler = 6;
constexpr int kNotesPerStep = 8;
constexpr uint8_t kSequencerNoteUnassigned = 200;
constexpr const char *kStepNoteNames[12] = {"C",  "C#", "D",  "D#", "E",  "F",
                                            "F#", "G",  "G#", "A",  "A#", "B"};

void clear_display(ssd1306_t *disp) {
    ssd1306_clear_square(disp, 0, 0, kDisplayWidth, kDisplayHeight);
}

void draw_title(ssd1306_t *disp, const char *title) {
    ssd1306_draw_string_inverted(disp, 8, 0, 1, title);
}

void draw_octave(ssd1306_t *disp, int8_t octave) {
    char octave_text[8];
    snprintf(octave_text, sizeof(octave_text), "Oct%+d", octave);
    ssd1306_draw_string(disp, 88, 2, 1, octave_text);
}

void draw_box_outline(ssd1306_t *disp, int x, int y, int width, int height) {
    ssd1306_draw_line(disp, x, y, x + width, y);
    ssd1306_draw_line(disp, x, y + height, x + width, y + height);
    ssd1306_draw_line(disp, x, y, x, y + height);
    ssd1306_draw_line(disp, x + width, y, x + width, y + height);
}

bool append_step_note(char *line, size_t line_size, int &pos,
                      const char *note_name, uint8_t channel) {
    const int written =
        snprintf(line + pos, line_size - static_cast<size_t>(pos), "%s(%d) ",
                 note_name, channel + 1);
    if (written < 0 ||
        static_cast<size_t>(written) >=
            line_size - static_cast<size_t>(pos)) {
        return false;
    }

    pos += written;
    return true;
}

void draw_noise_preview(ssd1306_t *disp, int x, int y, int width, int height,
                        uint16_t phase) {
    uint32_t seed = 0x13579BDFu ^ (static_cast<uint32_t>(phase) * 747796405u);
    const int midline = y + height / 2;
    int prev_y = midline;

    for (int i = 0; i < width; ++i) {
        seed = (seed * 1664525u) + 1013904223u;
        const int16_t sample = static_cast<int16_t>(seed >> 16);
        const int point_y =
            midline - ((static_cast<int32_t>(sample) * (height / 2 - 1)) /
                       32767);
        if (i > 0) {
            ssd1306_draw_line(disp, x + i - 1, prev_y, x + i, point_y);
        }
        prev_y = point_y;
    }
}

void draw_pink_noise_preview(ssd1306_t *disp, int x, int y, int width,
                             int height, uint16_t phase) {
    uint32_t seed = 0x2468ACE1u ^ (static_cast<uint32_t>(phase) * 2891336453u);
    const int midline = y + height / 2;
    int prev_y = midline;
    int32_t smooth = 0;

    for (int i = 0; i < width; ++i) {
        seed = (seed * 1664525u) + 1013904223u;
        const int16_t raw = static_cast<int16_t>(seed >> 16);
        smooth = (smooth * 3 + raw) >> 2;
        const int point_y =
            midline - ((smooth * (height / 2 - 1)) / 32767);
        if (i > 0) {
            ssd1306_draw_line(disp, x + i - 1, prev_y, x + i, point_y);
        }
        prev_y = point_y;
    }
}
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

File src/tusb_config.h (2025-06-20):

/*
 * The MIT License (MIT)
 *
 * Copyright (c) 2019 Ha Thach (tinyusb.org)
 *
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
 */

#ifndef _TUSB_CONFIG_H_
#define _TUSB_CONFIG_H_

#ifdef __cplusplus
extern "C" {
#endif

//--------------------------------------------------------------------
// COMMON CONFIGURATION
//--------------------------------------------------------------------

// defined by compiler flags for flexibility
#ifndef CFG_TUSB_MCU
#error CFG_TUSB_MCU must be defined
#endif

#if CFG_TUSB_MCU == OPT_MCU_LPC18XX || CFG_TUSB_MCU == OPT_MCU_LPC43XX ||      \
    CFG_TUSB_MCU == OPT_MCU_MIMXRT10XX || CFG_TUSB_MCU == OPT_MCU_NUC505 ||    \
    CFG_TUSB_MCU == OPT_MCU_CXD56
#define CFG_TUSB_RHPORT0_MODE (OPT_MODE_DEVICE | OPT_MODE_HIGH_SPEED)
#else
#define CFG_TUSB_RHPORT0_MODE OPT_MODE_DEVICE
#endif

#ifndef CFG_TUSB_OS
#define CFG_TUSB_OS OPT_OS_PICO
#endif

// Specifically define the port mode
// #define BOARD_TUD_RHPORT  0
// #define CFG_TUSB_RHPORT0_MODE (OPT_MODE_DEVICE | BOARD_TUD_MAX_SPEED)
// #elif BOARD_TUD_RHPORT == 1
// #define CFG_TUSB_RHPORT1_MODE (OPT_MODE_DEVICE | BOARD_TUD_MAX_SPEED)
// #endif

// CFG_TUSB_DEBUG is defined by compiler in DEBUG build
// #define CFG_TUSB_DEBUG           0

/* USB DMA on some MCUs can only access a specific SRAM region with restriction
 * on alignment. Tinyusb use follows macros to declare transferring memory so
 * that they can be put into those specific section. e.g
 * - CFG_TUSB_MEM SECTION : __attribute__ (( section(".usb_ram") ))
 * - CFG_TUSB_MEM_ALIGN   : __attribute__ ((aligned(4)))
 */
#ifndef CFG_TUSB_MEM_SECTION
#define CFG_TUSB_MEM_SECTION
#endif

#ifndef CFG_TUSB_MEM_ALIGN
#define CFG_TUSB_MEM_ALIGN __attribute__((aligned(4)))
#endif

//--------------------------------------------------------------------
// DEVICE CONFIGURATION
//--------------------------------------------------------------------

#ifndef CFG_TUD_ENDPOINT0_SIZE
#define CFG_TUD_ENDPOINT0_SIZE 64
#endif

//------------- CLASS -------------//
#define CFG_TUD_CDC 1
#define CFG_TUD_MSC 1
#define CFG_TUD_HID 0
#define CFG_TUD_MIDI 1
#define CFG_TUD_VENDOR 0

// MIDI FIFO size of TX and RX
#define CFG_TUD_MIDI_RX_BUFSIZE (TUD_OPT_HIGH_SPEED ? 512 : 64)
#define CFG_TUD_MIDI_TX_BUFSIZE (TUD_OPT_HIGH_SPEED ? 512 : 64)

// Size of the TX/RX buffers for CDC
#define CFG_TUD_CDC_RX_BUFSIZE (TUD_OPT_HIGH_SPEED ? 512 : 64)
#define CFG_TUD_CDC_TX_BUFSIZE (TUD_OPT_HIGH_SPEED ? 512 : 64)
#define CFG_TUD_CDC_EP_BUFSIZE (TUD_OPT_HIGH_SPEED ? 512 : 64)


#define CFG_TUD_MSC_EP_BUFSIZE  (4096)

// // We use a vendor specific interface but with our own driver
// // Vendor driver only used for Microsoft OS 2.0 descriptor
// #if !PICO_STDIO_USB_RESET_INTERFACE_SUPPORT_MS_OS_20_DESCRIPTOR
// #define CFG_TUD_VENDOR            (0)
// #else
// #define CFG_TUD_VENDOR            (1)
// #define CFG_TUD_VENDOR_RX_BUFSIZE  (256)
// #define CFG_TUD_VENDOR_TX_BUFSIZE  (256)
// #endif

// RHPort number used for device can be defined by board.mk, default to port 0
#ifndef BOARD_TUD_RHPORT
#define BOARD_TUD_RHPORT      0
#endif

#ifdef __cplusplus
}
#endif

#endif /* _TUSB_CONFIG_H_ */

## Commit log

2025-03-15 Staring the schematics in Kicad, DAC schematics completed with better LDO regulators
    [PicoSynth.kicad_pcb, PicoSynth.kicad_sch]
2025-03-15 Added some spice simulations i did in january for the analog low pass filter
2025-03-16 Some work on the simulation, filter is working but headphone driver not
2025-03-18 A lot of updates in the Schematic... To-Do: hot swaps in switches, SD card and I2C for screen
    [PicoSynth.kicad_pcb, PicoSynth.kicad_sch]
2025-03-18 add: polyphony! fixed point ftw!
    [main.cpp]
2025-03-19 SD card and i2c for display added, starting some component placement
    [PicoSynth.kicad_pcb, PicoSynth.kicad_sch]
2025-03-19 New horizontal layout
    [PicoSynth.kicad_pcb, PicoSynth.kicad_sch]
2025-03-20 add: filter test, sinc LUT and fixed_point header
2025-03-20 cheby filter 16 bit on the way
2025-03-23 This layout could work, need to ponder
    [PicoSynth.kicad_pcb, PicoSynth.kicad_sch, freerouting.dsn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]
2025-03-23 Deleted some unused files
    [freerouting.dsn, temp-freerouting.dsn]
2025-03-25 Basic routing almost complete: 6 more traces to go
    [PicoSynth.kicad_pcb, PicoSynth.kicad_sch]
2025-03-30 Routing Done, to-do: verify schematic and fix silkscreen
    [PicoSynth.kicad_pcb, PicoSynth.kicad_sch]
2025-03-30 Added schematic PDF
2025-03-31 TO-DO: fix silkscreen
    [PicoSynth.kicad_pcb, PicoSynth.kicad_sch]
2025-04-01 Finished layout, no errors in DRC, silkscreen aso finished
    [PicoSynth.kicad_pcb, PicoSynth.kicad_sch]
2025-04-02 Added bill of materials
    [PicoSynth.kicad_sch, PicoSynth_BOM.csv, PicoSynth_BOM.xlsx]
2025-04-15 Ready to order
    [PicoSynth-B_Cu.gbr, PicoSynth-B_Mask.gbr, PicoSynth-B_Paste.gbr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]
2025-05-02 Added bill of materials with link for the first prototypes
    [PicoSynth_BOM.csv, PicoSynth_BOM.xlsx, Pico_Synth_Ali_BOM.xlsx]
2025-05-09 ssd1306 added flip and rotate and all that
    [main.cpp]
2025-05-10 Create a hardware tester script in micropython
    [Pico_Synth_Ali_BOM.xlsx]
2025-05-15 switches and LEDS baby
2025-05-15 encoders baby
2025-05-17 encoder to change the wave-type
2025-05-18 ADSR encoder
2025-05-18 Filter Encoder
2025-05-19 Added some 3D models, .stl because .step are too large
    [PicoSynth.kicad_pcb]
2025-06-07 hardware encoder polling
    [PicoSynth.step, case.FCStd, case0.2-PicoSynth-back-cover.stl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]
2025-06-08 fix: out of tune (and overclock a little bit more)
    [main.cpp]
2025-06-08 midi / swiches flow menu
2025-06-08 sequencer hardware interrupts
2025-06-08 sequencer hardware interrupts and menu baby
2025-06-09 Fixing my mistakes, bad git user ig
    [HardwareManager.cpp]
2025-06-11 cleanup ui, still missing integration
    [Ui.cpp, main.cpp, main_menu.cpp]
2025-06-11 envelope uint8 steps
    [case0.3-PicoSynth-front-cover.stl]
2025-06-11 envelopes by midi
    [case2.FCStd]
2025-06-12 sequencer fix: pause and add channel
    [Sequencer.hpp]
2025-06-13 midi filter, other bug fixes
    [HardwareManager.cpp, main_menu.cpp]
2025-06-16 I2s pin definitions
2025-06-16 case v0.4
    [case0.3-PicoSynth-back-cover.stl, case0.3-PicoSynth-front-cover.stl, case2.FCStd]
2025-06-19 sd card sampler buffer
2025-06-19 sampler into switches and sequencer
2025-06-19 fix: sampler pop (correct header read)
    [main.cpp]
2025-06-20 Sampler Menu start
2025-06-20 Reading sample names not working yet
    [HardwareManager.cpp, Ui.cpp]
2025-06-20 rebase for the sampler menu
2025-06-21 fm edit menu, switches back to main
2025-06-21 Bug fixes in the choose menu
    [HardwareManager.cpp, fm_menu.cpp]
2026-04-03 Compiles for the Pico 2, added some effects (work in progress)
2026-04-08 Bug fixes and Presets!
    [HardwareManager.cpp]
2026-04-14 Added LFO, Reduced RAM usage overall, better sample playback, bug fixes
    [HardwareManager.cpp]
